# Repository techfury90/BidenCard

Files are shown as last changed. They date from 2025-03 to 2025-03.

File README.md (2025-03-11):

# Biden Card
Partially cost reduced/modernized Sinclair QL Trump Card clone with bonus Dark Brandon meme.

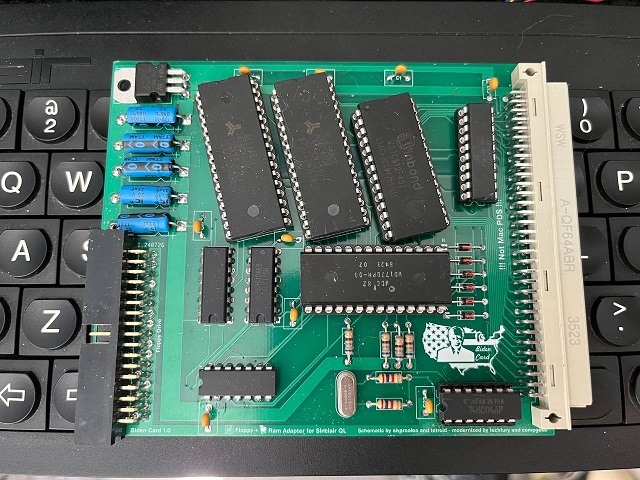
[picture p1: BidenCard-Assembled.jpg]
Assembled Biden Card Photo


# Background
I originally started this project in late 2023 because real Trump Cards were getting difficult to obtain, and I wanted one for my QLs. 

Alvaro had previously successfully cloned the board, but there were timing-related issues with substituting the PALs for GALs. Analysis of the situation revealed that the issue related to DRAM control timing. Since 41256 DRAM is no longer made, I decided to move to AS6C4008 4mbit SRAM. The resulting logic simplification also eliminated the need for GAL 2, and paring down GAL 1's DRAM-related functions allowed me to fit the new SRAM decode logic into GAL 1, thereby eliminating GAL 2 entirely. 

The end result is 100% compatible with the Trump Card, but only costs about $50 USD to manufacture.

This design is a bit quick/rudimentary/slapdash- in particular, these low-hanging fruits exist for optimization: 
- Replace DIP AS6C4008s with suitable SMD SRAM. Do note that I grounded out OE (output enable) and use only CS to access the SRAM- most SRAMs can handle this but please check the datasheet!
- Redo axial caps with radials (this was really just cargo-culted from the original design to get a viable prototype working quickly)
- Replace 7805 with a more efficient regulator (even with the 7805, however, power consumption is a fraction of the original Trump Card!)

# Credits
- Alvaro Alea for reverse engineering the Trump Card 2 schematic (the basis of this project)
- Tetroid for reverse engineering the PAL/GAL logic equations. His equations were the basis of mine, particularly in regards to the P13/P16 ROM shadowing bodge needed to make pre-Minerva ROMs recognize the ROM.
- Compgeke for doing the PCB layout (I have not quite honed that skill yet... this is my first DIY PCB project of this scale!)

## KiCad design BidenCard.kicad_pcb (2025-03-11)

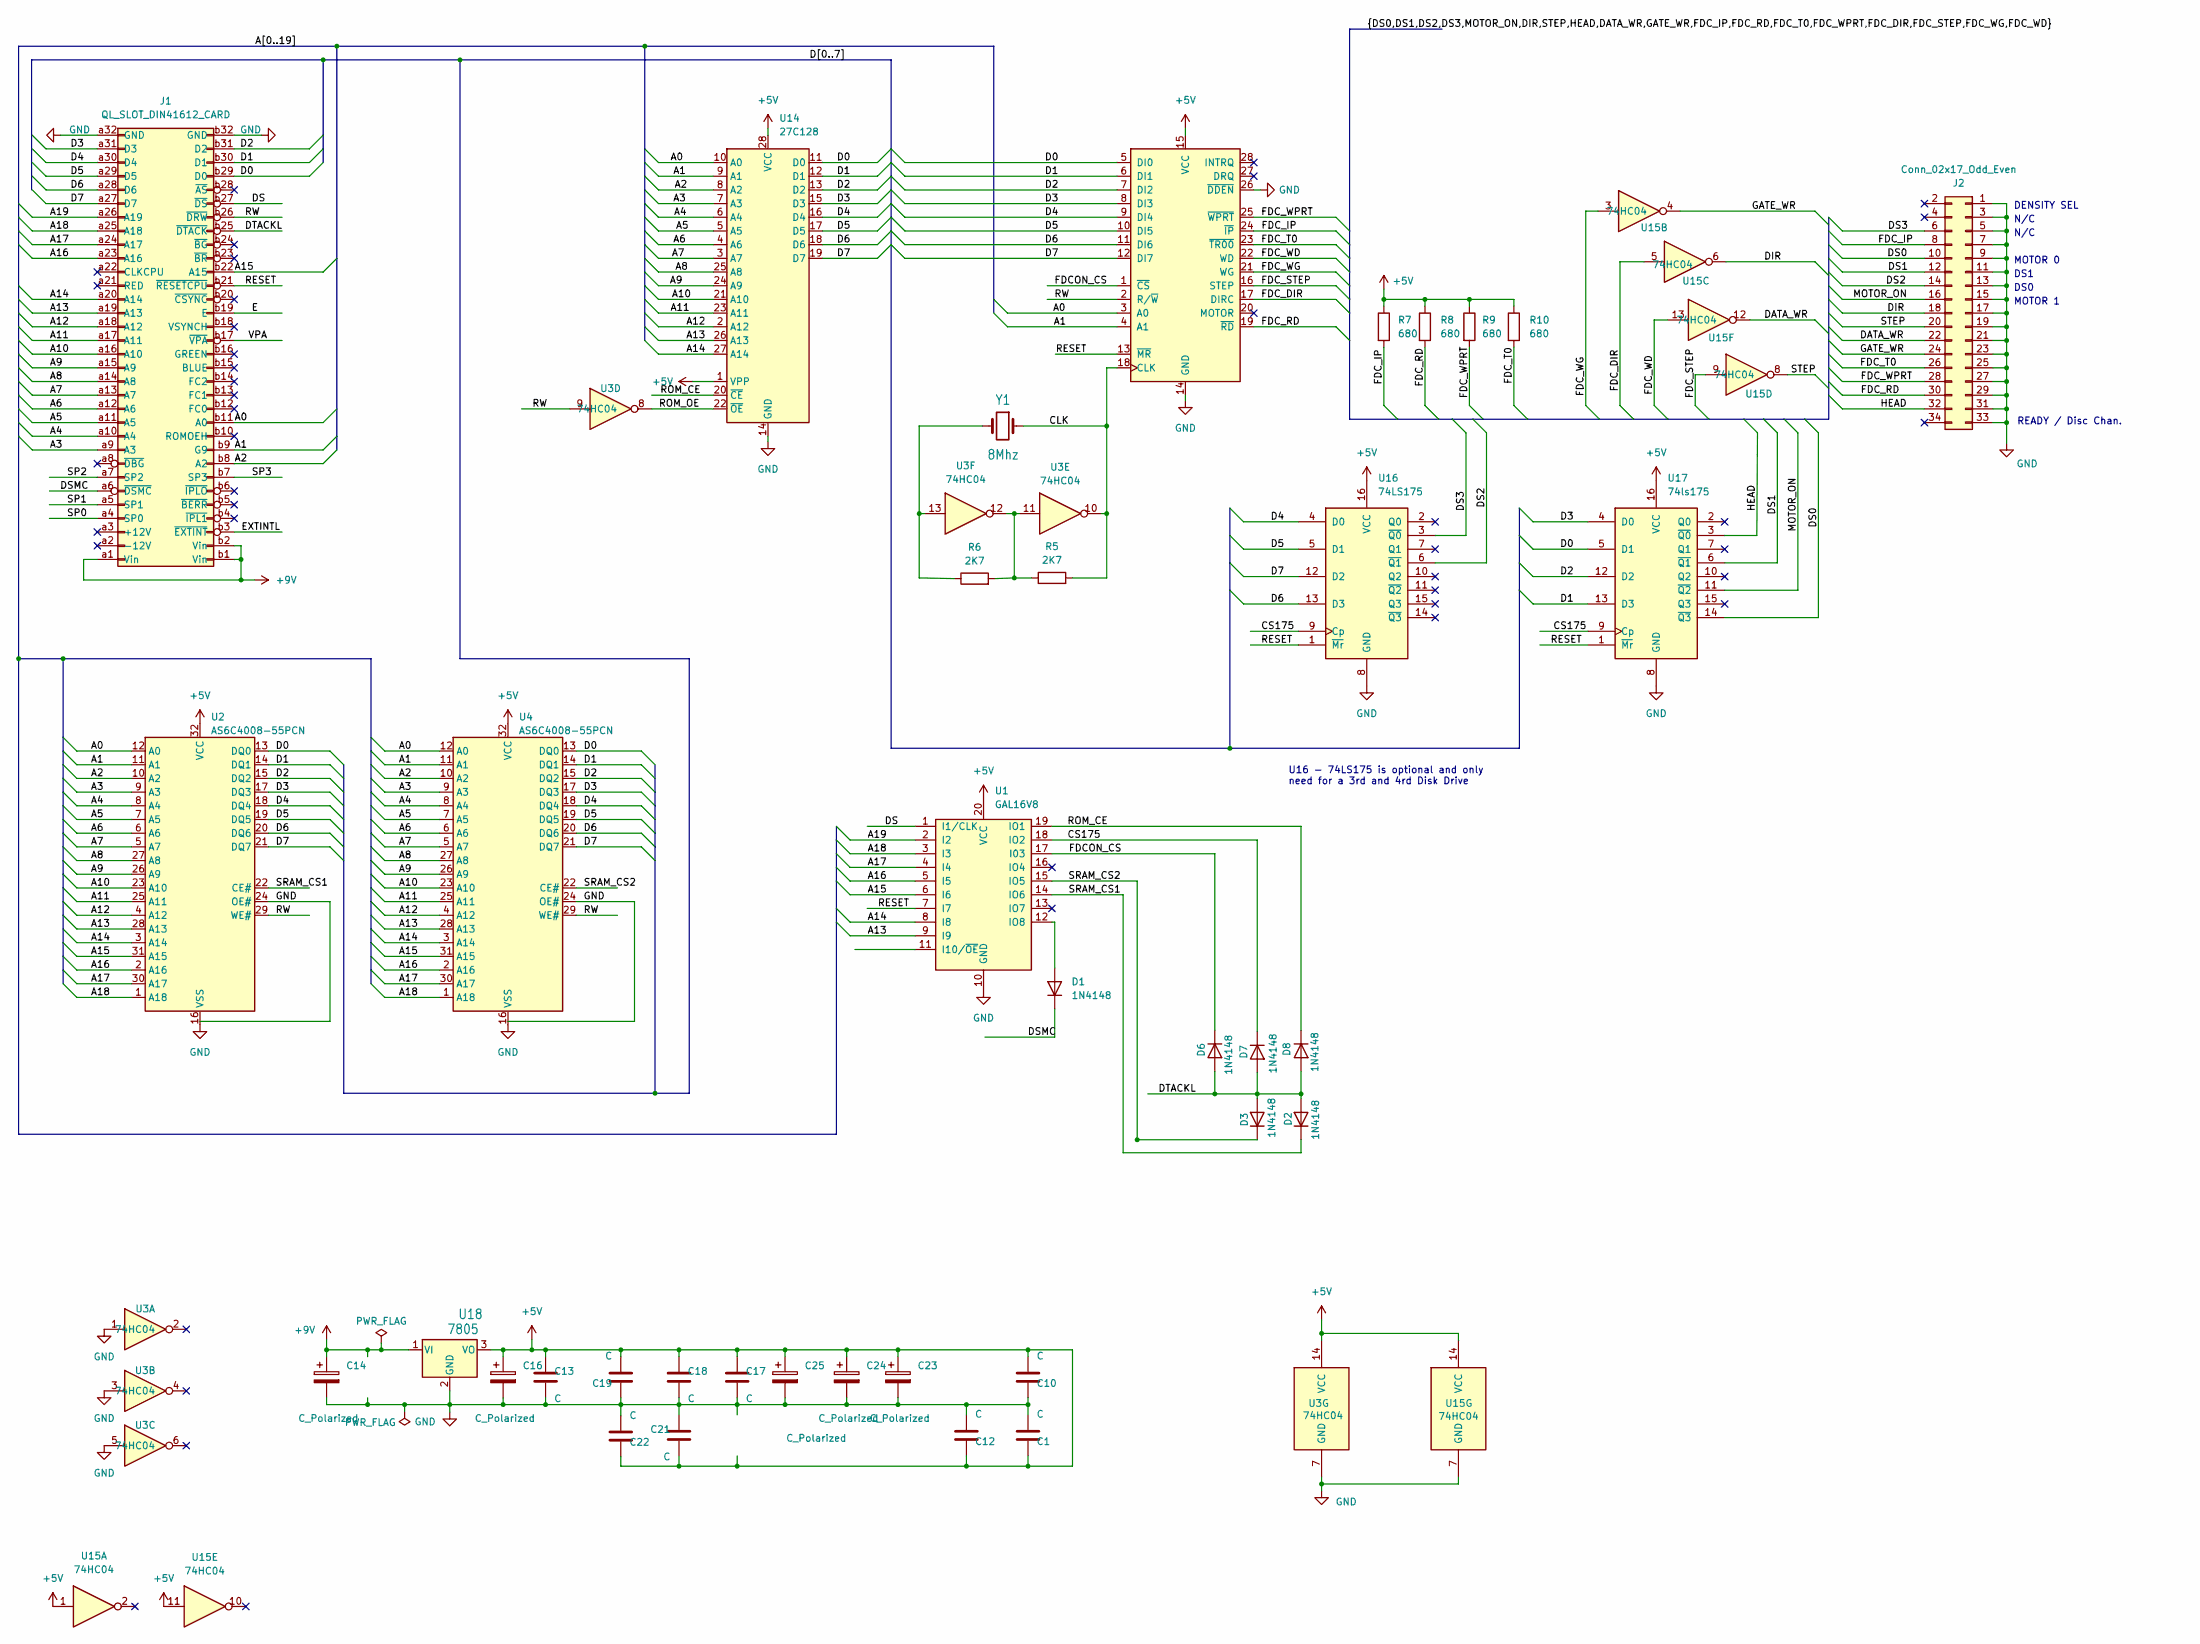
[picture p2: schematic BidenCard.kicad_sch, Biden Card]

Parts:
C1, C10, C12, C17, C18, C19, C21, C22: C; C_Disc_D7.5mm_W4.4mm_P5.00mm
C13: C; C_Disc_D5.1mm_W3.2mm_P5.00mm
C14, C16, C23, C24, C25: C_Polarized; CP_Axial_L11.0mm_D5.0mm_P18.00mm_Horizontal
D1, D2, D3, D6, D7, D8: 1N4148; D_DO-35_SOD27_P10.16mm_Horizontal
J1: QL_SLOT_DIN41612_CARD; DIN41612_B_2x32_Male_Horizontal_THT
J2: Conn_02x17_Odd_Even; PinHeader_2x17_P2.54mm_Horizontal
R5, R6: 2K7; R_Axial_DIN0207_L6.3mm_D2.5mm_P10.16mm_Horizontal
R7, R8, R9, R10: 680; R_Axial_DIN0207_L6.3mm_D2.5mm_P10.16mm_Horizontal
U1: GAL16V8; DIP-20_W7.62mm
U2, U4: AS6C4008-55PCN; DIP-32_W15.24mm
U3, U15: 74HC04; DIP-14_W7.62mm
U13: FDC_WD1772; DIP-28_W15.24mm
U14: 27C128; DIP-28_W15.24mm
U16: 74LS175; DIP-16_W7.62mm
U17: 74ls175; DIP-16_W7.62mm
U18: 7805; TO-220-3_Horizontal_TabDown
Y1: 8Mhz; Crystal_HC18-U_Vertical

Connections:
+5V: C1.1, C10.2, C12.1, C13.1, C16.1, C17.1, C18.1, C19.2, C21.2, C22.1, C23.1, C24.1, C25.1, R7.1, R8.1, R9.1, R10.1, U1.20 (VCC), U2.32 (VCC), U3.14 (VCC), U4.32 (VCC), U13.15 (VCC), U14.1 (VPP), U14.28 (VCC), U15.1, U15.11, U15.14 (VCC), U16.16 (VCC), U17.16 (VCC), U18.3 (VO)
+9V: C14.1, J1.a1 (Vin), J1.b1 (Vin), J1.b2 (Vin), U18.1 (VI)
/A0: J1.b11 (A0), U2.12 (A0), U4.12 (A0), U13.3 (A0), U14.10 (A0)
/A1: J1.b9 (G9), U2.11 (A1), U4.11 (A1), U13.4 (A1), U14.9 (A1)
/A2: J1.b8 (A2), U2.10 (A2), U4.10 (A2), U14.8 (A2)
/A3: J1.a9 (A3), U2.9 (A3), U4.9 (A3), U14.7 (A3)
/A4: J1.a10 (A4), U2.8 (A4), U4.8 (A4), U14.6 (A4)
/A5: J1.a11 (A5), U2.7 (A5), U4.7 (A5), U14.5 (A5)
/A6: J1.a12 (A6), U2.6 (A6), U4.6 (A6), U14.4 (A6)
/A7: J1.a13 (A7), U2.5 (A7), U4.5 (A7), U14.3 (A7)
/A8: J1.a14 (A8), U2.27 (A8), U4.27 (A8), U14.25 (A8)
/A9: J1.a15 (A9), U2.26 (A9), U4.26 (A9), U14.24 (A9)
/A10: J1.a16 (A10), U2.23 (A10), U4.23 (A10), U14.21 (A10)
/A11: J1.a17 (A11), U2.25 (A11), U4.25 (A11), U14.23 (A11)
/A12: J1.a18 (A12), U2.4 (A12), U4.4 (A12), U14.2 (A12)
/A13: J1.a19 (A13), U1.9 (I9), U2.28 (A13), U4.28 (A13), U14.26 (A13)
/A14: J1.a20 (A14), U1.8 (I8), U2.3 (A14), U4.3 (A14), U14.27 (A14)
/A15: J1.b22 (A15), U1.6 (I6), U2.31 (A15), U4.31 (A15)
/A16: J1.a23 (A16), U1.5 (I5), U2.2 (A16), U4.2 (A16)
/A17: J1.a24 (A17), U1.4 (I4), U2.30 (A17), U4.30 (A17)
/A18: J1.a25 (A18), U1.3 (I3), U2.1 (A18), U4.1 (A18)
/A19: J1.a26 (A19), U1.2 (I2)
/CLK: R5.2, U3.10, U13.18 (CLK), Y1.1
/CS175: D7.1 (K), U1.18 (IO2), U16.9 (Cp), U17.9 (Cp)
/D0: J1.b29 (D0), U2.13 (DQ0), U4.13 (DQ0), U13.5 (DI0), U14.11 (D0), U17.5 (D1)
/D1: J1.b30 (D1), U2.14 (DQ1), U4.14 (DQ1), U13.6 (DI1), U14.12 (D1), U17.13 (D3)
/D2: J1.b31 (D2), U2.15 (DQ2), U4.15 (DQ2), U13.7 (DI2), U14.13 (D2), U17.12 (D2)
/D3: J1.a31 (D3), U2.17 (DQ3), U4.17 (DQ3), U13.8 (DI3), U14.15 (D3), U17.4 (D0)
/D4: J1.a30 (D4), U2.18 (DQ4), U4.18 (DQ4), U13.9 (DI4), U14.16 (D4), U16.4 (D0)
/D5: J1.a29 (D5), U2.19 (DQ5), U4.19 (DQ5), U13.10 (DI5), U14.17 (D5), U16.5 (D1)
/D6: J1.a28 (D6), U2.20 (DQ6), U4.20 (DQ6), U13.11 (DI6), U14.18 (D6), U16.13 (D3)
/D7: J1.a27 (D7), U2.21 (DQ7), U4.21 (DQ7), U13.12 (DI7), U14.19 (D7), U16.12 (D2)
/DATA_WR: J2.22, U15.12
/DIR: J2.18, U15.6
/DS: J1.b27 (~DS), U1.1 (I1/CLK)
/DS0: J2.10, U17.14 (~Q3)
/DS1: J2.12, U17.6 (~Q1)
/DS2: J2.14, U16.6 (~Q1)
/DS3: J2.6, U16.3 (~Q0)
/DSMC: D1.1 (K), J1.a6 (~DSMC)
/DTACKL: D2.2 (A), D3.2 (A), D6.2 (A), D7.2 (A), D8.2 (A), J1.b25 (~DTACK)
/E: J1.b19 (E)
/EXTINTL: J1.b3 (~EXTINT)
/FDCON_CS: D6.1 (K), U1.17 (I03), U13.1 (~CS)
/FDC_DIR: U13.17 (DIRC), U15.5
/FDC_IP: J2.8, R7.2, U13.24 (~IP)
/FDC_RD: J2.30, R8.2, U13.19 (~RD)
/FDC_STEP: U13.16 (STEP), U15.9
/FDC_T0: J2.26, R10.2, U13.23 (~TR00)
/FDC_WD: U13.22 (WD), U15.13
/FDC_WG: U13.21 (WG), U15.3
/FDC_WPRT: J2.28, R9.2, U13.25 (~WPRT)
/GATE_WR: J2.24, U15.4
/HEAD: J2.32, U17.3 (~Q0)
/MOTOR_ON: J2.16, U17.11 (~Q2)
/RESET: J1.b21 (~RESETCPU), U1.7 (I7), U13.13 (~MR), U16.1 (~Mr), U17.1 (~Mr)
/ROM_CE: D8.1 (K), U1.19 (IO1), U14.20 (~CE)
/ROM_OE: U3.8, U14.22 (~OE)
/RW: J1.b26 (~DRW), U2.29 (WE#), U3.9, U4.29 (WE#), U13.2 (R/~W)
/SP0: J1.a4 (SP0)
/SP1: J1.a5 (SP1)
/SP2: J1.a7 (SP2)
/SP3: J1.b7 (SP3)
/SRAM_CS1: D2.1 (K), U1.14 (IO6), U2.22 (CE#)
/SRAM_CS2: D3.1 (K), U1.15 (IO5), U4.22 (CE#)
/STEP: J2.20, U15.8
/VPA: J1.b17 (~VPA)
GND: C1.2, C10.1, C12.2, C13.2, C14.2, C16.2, C17.2, C18.2, C19.1, C21.1, C22.2, C23.2, C24.2, C25.2, J1.a32 (GND), J1.b32 (GND), J2.1, J2.3, J2.5, J2.7, J2.9, J2.11, J2.13, J2.15, J2.17, J2.19, J2.21, J2.23, J2.25, J2.27, J2.29, J2.31, J2.33, U1.10 (GND), U2.16 (VSS), U2.24 (OE#), U3.1, U3.3, U3.5, U3.7 (GND), U4.16 (VSS), U4.24 (OE#), U13.14 (GND), U13.26 (~DDEN), U14.14 (GND), U15.7 (GND), U16.8 (GND), U17.8 (GND), U18.2 (GND)
unnamed: D1.2 (A), U1.12 (IO8)
unnamed: R5.1, R6.2, U3.11, U3.12
unnamed: R6.1, U3.13, Y1.2

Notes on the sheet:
MOTOR 0
DS0
DS1
READY / Disc Chan.
MOTOR 1
U16 - 74LS175 is optional and only need for a 3rd and 4rd Disk Drive
N/C
DENSITY SEL

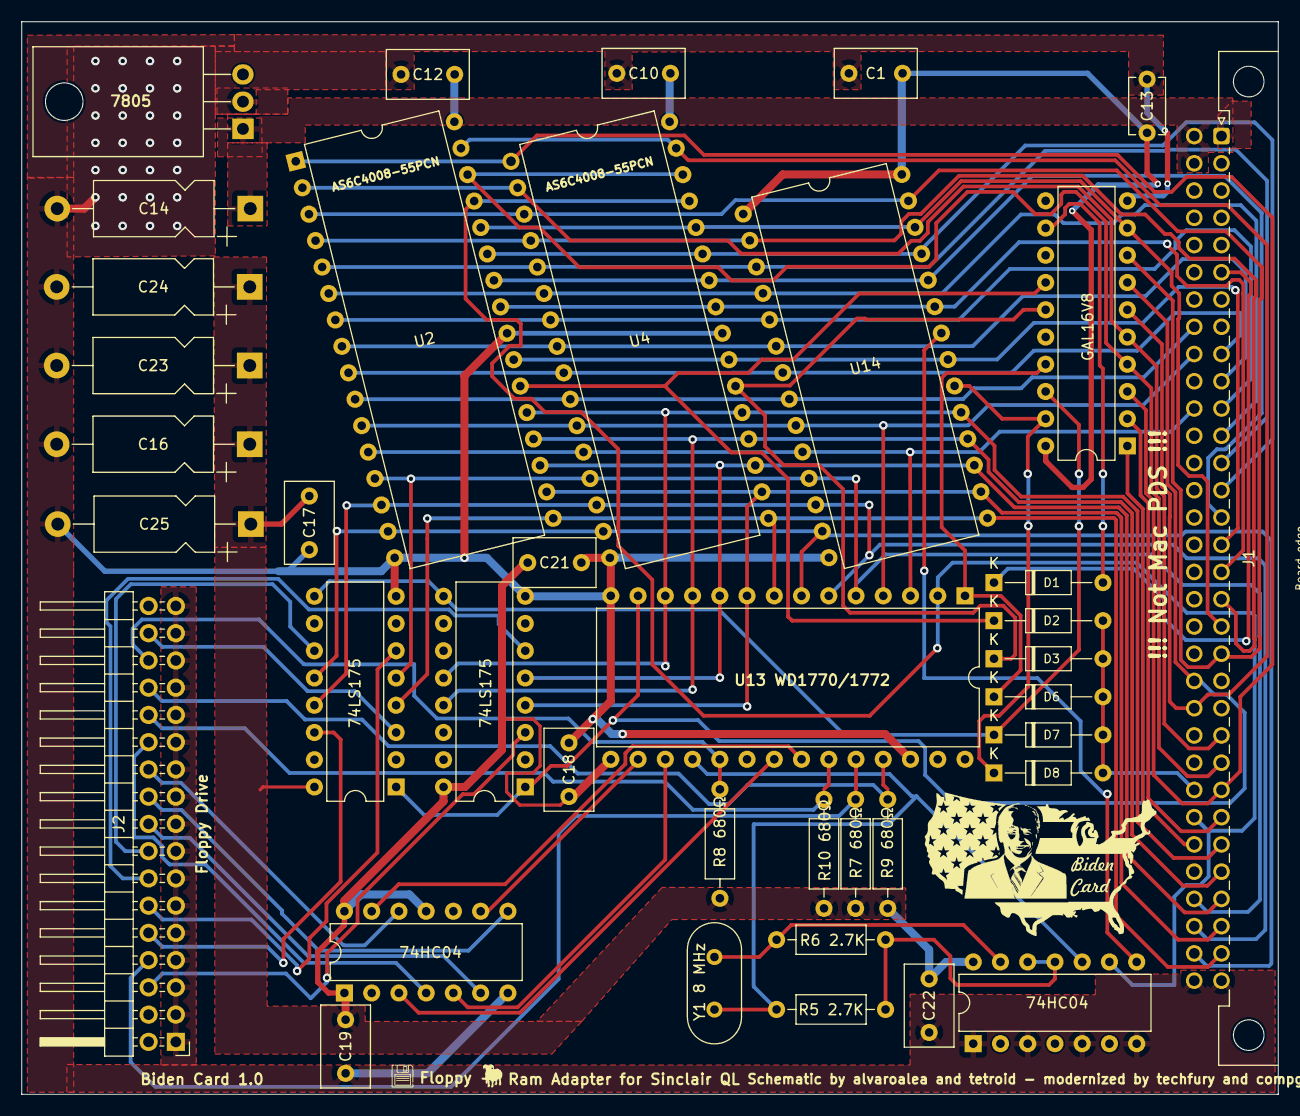
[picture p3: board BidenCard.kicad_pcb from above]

Board: 2 copper layers, 117.2 x 100.0 mm, 39 parts (0 on the bottom side), 64 nets.

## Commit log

2025-03-11 add project (with ECO for U3)
    [BidenCard.kicad_pcb, BidenCard.kicad_sch]
2025-03-11 update PCB silkscreen for revision 2
    [BidenCard.kicad_pcb]
2025-03-11 add Gerbers for JLC fabrication
    [BidenCard-B_Cu.gbr, BidenCard-B_Mask.gbr, BidenCard-B_Paste.gbr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]
2025-03-11 add photo of assembled card
